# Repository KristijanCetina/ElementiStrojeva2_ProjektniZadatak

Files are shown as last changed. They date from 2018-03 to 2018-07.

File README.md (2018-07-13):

# ElementiStrojeva2_ProjektniZadatak
Projektni zadatak iz kolegija Elementi strojeva 2

Proračun i konstrukcija strojnog sklopa cilindričnog zupčanika s ravnim zubima, vratila i uležištenja unutar prijenosnika snage.
[PDF verzija proračuna s nacrtom](https://github.com/KristijanCetina/ElementiStrojeva2_ProjektniZadatak/blob/master/ProjektniZadatak_KristijanCetina.pdf)

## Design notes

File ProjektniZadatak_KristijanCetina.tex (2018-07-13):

\documentclass[11pt,a4paper]{article}
\usepackage[utf8]{inputenc}
\usepackage[croatian]{babel}
\usepackage{amsmath, amsfonts, amssymb}
\usepackage{tocloft}
\usepackage[hidelinks]{hyperref}
\usepackage[section]{placeins}
\usepackage{graphicx}
\usepackage{float}
\usepackage[final]{pdfpages}
\bibliographystyle{ieeetr}%ieeetr, abbrv
\renewcommand{\cftsecleader}{\cftdotfill{\cftdotsep}}

\newcommand{\kolegij}{Elementi strojeva 2}
\newcommand{\naslovRada}{Projektni zadatak}
\newcommand{\mailFriendlynaslovRada}{Elementi strojeva 2, projektni zadatak}

\author{Kristijan Cetina\footnote{\href{mailto:kcetina@politehnika-pula.hr?subject=\mailFriendlynaslovRada}{kcetina@politehnika-pula.hr}, JMBAG: 2424011721}}
\title{\kolegij \\ \naslovRada}
\date{Pula, \today}

\begin{document}

\begin{titlepage}
\clearpage
\begin{center}
\begin{Huge}
POLITEHNIKA PULA\\
\end{Huge}
\begin{LARGE}
Visoka tehničko-poslovna škola s p.j.\\
Stručni studij politehnike\\
\end{LARGE}
\end{center}
\vspace{3cm}
{\let\newpage\relax\maketitle}
\thispagestyle{empty}
\vfill
\begin{abstract}
U ovom radu predstavljam proračun strojnog sklopa - vratila prijenosnika snage i pripadajućih ležajeva koji je zadan kao sastavni dio kolegija Elementi strojeva 2.
\end{abstract}
\end{titlepage}

\tableofcontents
%\listoftables	%ako ih ima puno prebaci na kraj dokumenta
%\listoffigures	%ako ih ima puno prebaci na kraj dokumenta

\newpage
\section{Uvod}
Ovaj projektni zadatak nastoj je kao obavezni zadatak u sklopu kolegija Elementri strojeva 2 koji se održava pod vodstvom prof. dr. sc. Božidara Križana na stručnom studiju politehnike na Politehnici Pula.

U ovom radu obrađen je proračun vratila prijenosnika snage s pripadajućim ležajevima. Prema zadatku bilo je potrebno odrediti dimenzije vratila i ležaja te odabrati prikladni ležaj u ondnosu na postavljene zahtjeve prenosa snage i traženu minimalnu trajnost.

\newpage
\section{Proračun sklopa}
\subsection{Zadani parametri}
Prema projektnom zadatku zadani su sljedeći parametri sklopa:\\
\begin{tabbing}
\hspace{260pt}\=\kill
 Snaga koju prenose zupčanik i vratilo \> $P=23 kW$ \\ 
 Brzina vrtnje \> $800 min^{-1}$ \\ 
 Materijal vratila \> Ck45 \\
 Korjeni promjer zupčanika \> $d_f=96,25mm$ \\ 
 Diobeni promjer zupčanika \> $d=110mm$ \\ 
 Tjemeni promjer zupčanika \> $d_a=121mm$ \\ 
 Širina zupčanika \> $b_z=115mm$ \\ 
 Faktor sigurnosti \> $\nu_d=1,3$ \\ 
 Hrapavost površine na kritičnim mjestima \> $R_a=0,8\mu m$ \\ 
 Razmak ležajeva \> $l=165mm$ \\ 
 Razmak između središta ležaja A\\ i središta zupčanika \> $a=80mm$ \\ 
 Minimalna trajnost ležajeva \> $L_{10h min}=12000 sati$
\end{tabbing}
Mehanička svojstva korištenog materijala su sljedeća:\\
\begin{align*}
R_{dt0}&=340 \textstyle\frac{N}{mm^2}\\
R_{ds-1}&=370 \textstyle\frac{N}{mm^2}\\
R_e&=490 \textstyle\frac{N}{mm^2}\\
R_m&=700 \textstyle\frac{N}{mm^2}
\end{align*}
 
\subsection{Projektni proračun sklopa}
U projektnom praračunu sklopa ne uzima se u obzir svi detalji sklopa kao niti koncentracije lokalnog naprezanja, ali se zato uzima značajno veći faktor sigurnosti kako bi kompenzirali za izostavljene faktore. U projektnom proračunu za određivanje početnog promjera vratila uzeti su u obzir samo snaga koja se prenosi i materijal od kojeg se izrađuje vratilo. Kao mjerodavne vrijednosti uzeto je torzijsko naprezanje koje mora biti manje od dopuštenog, a faktor sigurnosti je usvojen $\nu=12$.
Kao glavni uvjet uzet je kriterij čvrstoće pri kojem torzijsko naprezanje mora biti manje od dopuštenog pri čemu torzijsko naprezanje možemo izraziti pomoću izraza
\begin{equation}
\tau_t=\dfrac{T}{W_p}\label{equ:tangencijalnoNaprezanje}
\end{equation}
pri čemu je $W_p$ za okrugli puni popreči presjek jednak
\begin{equation}
W_p=\frac{d_1^3 \cdot \pi}{16}
\end{equation}
Okretni moment koji se prenosi izračunat je pomoću sljedećeg izraza
\begin{equation}
T=\frac{P}{\omega}\label{equ:okretniMoment}
\end{equation}
pri čemu je obodna brzina $\omega=2 \cdot \pi \cdot n$, a $n$ je izražen u okretajima u sekundi $[s^{-1}]$.
Uvršavanjem poznatih podataka u \eqref{equ:okretniMoment} dobije se okretni moment
\begin{align*}
T&=\frac{60 \cdot 23 \cdot 10^3}{2 \cdot \pi \cdot 800}\\
T&=\textbf{274,5 Nm}
\end{align*}
Promjer vratila je izračunat pomoću izraza
\begin{equation}
d_1 \geq \sqrt[3]{\dfrac{16 \cdot T \cdot \nu}{R_{dt0} \cdot \pi}} \label{equ:pocetniPromjer}
\end{equation}

Uvršavanjem poznatih podataka u izraz \eqref{equ:pocetniPromjer} dobije se početni promjer vratila $d_1$
\begin{align*}
d_1&\geq \sqrt[3]{\dfrac{16 \cdot 274,5\cdot 10^3 \cdot 12}{340 \cdot \pi}}\\
d_1&\geq \mathbf{36,68 mm} 
\end{align*}

\subsection{Konstruiranje sklopa}
Prema tablici standardnih dimenzija krajeva cilindričnog vratila prema normi DIN 748 usvojena je dimenzija \textbf{38x80 DIN 748} ($\phi38k6$). Maksimalni radijus prijelaza je $r_{max}=1 mm$.

Prema tablici standardnih dimenzija uložnih pera po DIN 6885 normi usvojeno je pero 
$\mathbf{DIN6885-A 10 \times 8 \times 70-E295}$ s dubinom utora u vratilu $t_1=5mm$.
Dimenzija $d_2$ je zbog standardnih dimenzija ležajeva usvojena $\mathbf{d_2=45mm}$
\subsubsection*{Žlijeb za izlaz alata}
Usvojeme dimenzije žlijeba za izlaz alata prema $d_2$ su $\mathbf{DIN \, 509-E \, 0,6 \times 0,3}$ ($\rho_1=0,6mm$, $t_1=0,3mm$). Na slici \ref{izlazAlata} prikazan je žlijeb za izlaz alata.
\begin{figure}[H]
\centering
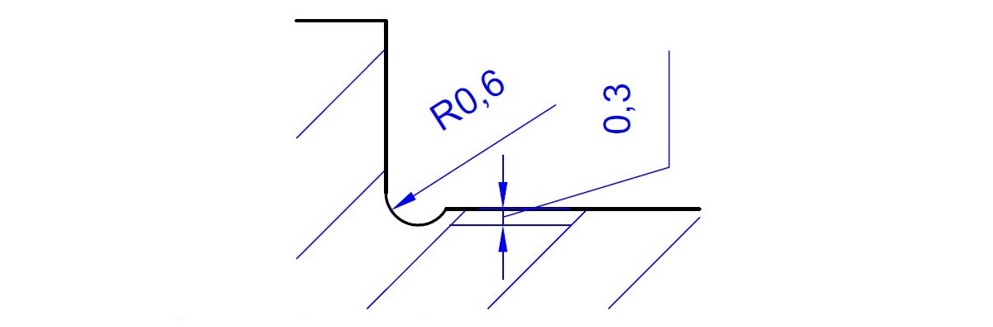
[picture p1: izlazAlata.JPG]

\caption{Skica žlijeba za izlaz alata}\label{izlazAlata}
\end{figure}
\subsubsection*{Visina bočnog oslonca ležaja}
Kao vrijednost visine bočnog oslonca ležaja usvojena je vrijednost $h=3,5mm$.
Promjer $d_3$ je izračunat kao $d_3=d_2+2 \cdot h = \mathbf{52mm}$.
Vrijednost radijusa zakrivljenja $\rho_2$ je usvojen $\rho_2=5mm$.

\subsection{Proračun reakcija u ležajevima}
Tangencijalna sila između zupčanika je izračunata pomoću momenta koji se prenosi i promjera zupčanika
\begin{align*}
F_t&=\frac{2T}{d}\\
F_t&=\frac{2 \cdot 274,5 \cdot 10^3}{110}\\
F_t&=\textbf{4990,9N}
\end{align*}
Radijalna sila je izračunata pomoću tangencijalne sile i poznatog kuta zahvata zubaca zupčanika koji iznosi $\alpha_n=20^\circ$
\begin{align*}
F_r&=F_t \cdot \tan \alpha_n\\
F_r&=4990,9 \cdot \tan 20^\circ\\
F_r&=\textbf{1816,5N}
\end{align*}
Kako sile mođusobno djeluju pod pravim kutem njihova rezultanta se može izračunati po Pitagorinom poučku kao korijen zbroja kvadrata sila
\begin{align*}
F&=\sqrt{F_t^2 + F_r^2}\\
F&=\sqrt{4990,9^2 + 1816,5^2}\\
F&=\textbf{5311,2N}
\end{align*}
Reakcija u osloncu $B$ izračunata je pomoću uvijeta ravnoteže sume momenata oko oslonva $A$
\begin{align*}
F_B&=\frac{F \cdot 80}{168}\\
F_B&=\frac{5311,2N \cdot 80}{168}\\
F_B&=\textbf{2575,1N}
\end{align*}
rakcija u osloncu $A$ izračunata je pomoću uvijeta ravnoteže sustava u kojem je suma sila i reakcija jednaka nuli
\begin{align*}
F_A&=F-F_B\\
F_A&=5311,2-2575,1\\
F_A&=\textbf{2736,1N}
\end{align*}

\subsection{Izbor valjnih ležajeva i proračun stvarne trajnosti}
Trajnost ležajeva se može proračunati po izrazu
\begin{equation}
L_{10h}=\left(\frac{C}{F} \cdot f_t \right)^p \cdot \frac{10^6}{60 \cdot n}
\label{equ:trajnostLezaja}
\end{equation}
pri čemu je $C$ - dinamička nosivost ležaja, $p$ - eksponent vijeka trajanja. Za kuglične ležajeve $p=3$ i $f_t$ - temperaturni faktor. Za $\vartheta < 150^\circ C \Rightarrow f_t=1$.

Iz izraza \eqref{equ:trajnostLezaja} može se izračunati minimalna potrebna dimanička nosivost ležaja
\begin{align*}
C&=\frac{F}{f_t} \cdot \sqrt[3]{\frac{L_{10h} \cdot 60 \cdot n}{10^6}}\\
C&=\frac{2736,1}{1} \cdot \sqrt[3]{\frac{12000 \cdot 60 \cdot 800}{10^6}}\\
C&\cong \mathbf{22,8kN}
\end{align*}
Nakon pregleda kataloških podataka dostupnih ležajeva odabran je ležaj \textbf{SKF 6209} koji ima dinamičku nosivost od $C=35,1kN$.

\begin{figure}[!h]
\centering
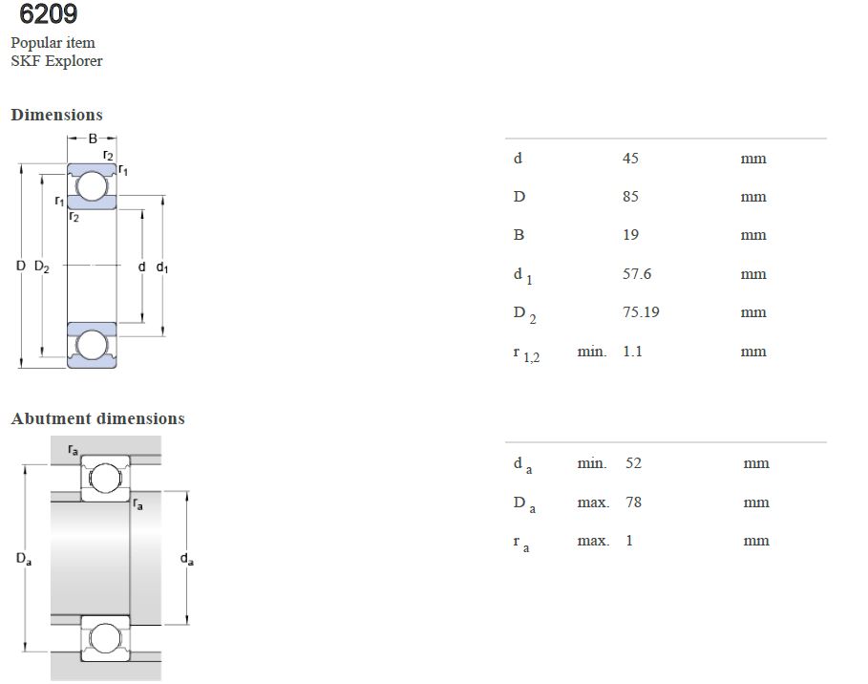
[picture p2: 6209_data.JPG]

\caption{Tehnički podaci odabranog ležaja SKF 6209}\label{6208data}
\end{figure}

\subsubsection*{Proračun stvarne trajnosti}
Po izrazu \eqref{equ:trajnostLezaja} sada se može izračunati stvarna trajnost za odabrani ležaj
\begin{align*}
L_{10h}&=\left(\frac{35100}{2736,1} \cdot 1 \right)^3 \cdot \frac{10^6}{60 \cdot 800}\\
L_{10h}&=\mathbf{43983\, h}
\end{align*}

\newpage

\subsection{Proračun momenata savijanja i naprezanja}
U nastavku su dani proračuni momenata savijanja i naprezanja za svaki kritični presjek nazanačen na slici \ref{KriticniPresjeci}.
\begin{figure}[h]
\centering
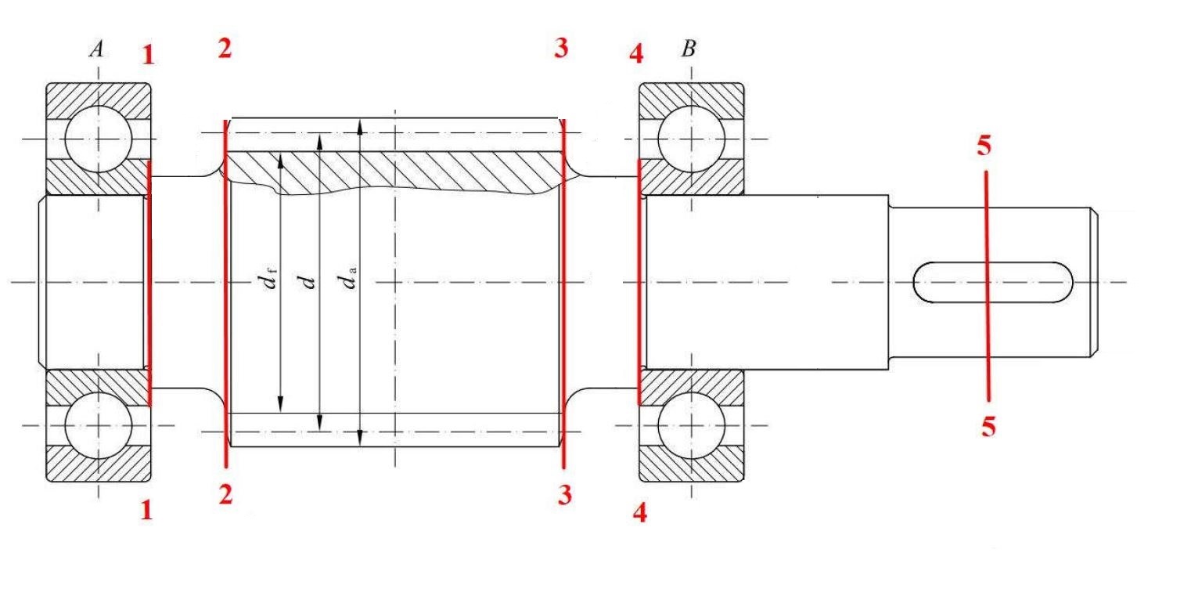
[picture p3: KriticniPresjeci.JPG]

\caption{Prikaz kritičnih presjeka na vratilu}\label{KriticniPresjeci}
\end{figure}
\begin{align*}
M_{S1}=F_A \cdot \frac{B}{2}=2736,1 \cdot \frac{19}{2}&=25933Nmm\\
M_{S2}=F_A \cdot \left(a- \frac{b_z}{2}\right)=2736,1 \cdot \left(80- \frac{115}{2}\right)&=61562,3Nmm\\
M_{S3}=F_B \cdot \left(l-a- \frac{b_z}{2}\right)=2575,1 \cdot \left(165-80- \frac{115}{2}\right)&=70815,3Nmm\\
M_{S4}=F_B \cdot \frac{B}{2}=2575,1 \cdot \frac{19}{2}&=24463,5Nmm\\
M_{S5}&=0
\end{align*}

\subsubsection*{Geometrijske karakteristike poprečnih presjeka - $W$}
\begin{align*}
W_1=W_4=\frac{d_2^3 \cdot \pi}{32}=\frac{45^3 \cdot \pi}{32}&=8946,2mm^3\\
W_2=W_3=\frac{d_3^3 \cdot \pi}{32}=\frac{52^3 \cdot \pi}{32}&=13804,2mm^3
\end{align*}
\subsubsection*{Polarni momenti otpora - $W_p$}
\begin{align*}
W_{p2}=W_{p3}=\frac{d_3^3 \cdot \pi}{16}=\frac{52^3 \cdot \pi}{16}&=27608,3mm^3\\
W_{p4}=\frac{d_2^3 \cdot \pi}{16}=\frac{45^3 \cdot \pi}{16}&=17892,4mm^3\\
W_{p5}=\frac{(d_1-t_1)^3 \cdot \pi}{16}=\frac{(38-5)^3 \cdot \pi}{16}&=7056,2mm^3
\end{align*}
\subsubsection*{presjek 1-1}
$$
\sigma_{s1}=\frac{M_{S1}}{W_1}=\frac{25933}{8946,2}=\mathbf{2,9\textstyle\frac{N}{mm^2}}
$$
\subsubsection*{presjek 2-2}
\begin{align*}
\sigma_{s2}=\frac{M_{S2}}{W_2}=\frac{61562,3}{13804,2}&=4,6\textstyle\frac{N}{mm^2}\\
\tau_{t2} =\frac{T}{W_{p2}}=\frac{274,5 \cdot 10^3}{27608,3}&=9,9\textstyle\frac{N}{mm^2}\\
\sigma_{ekv2}=\sqrt{\sigma_{s2}^2+3 \cdot (0,7 \cdot \tau_{t2})^2}\\
\sigma_{ekv2}=\sqrt{4,6^2+3 \cdot (0,7 \cdot 9,9)^2}&=\mathbf{12,9\textstyle\frac{N}{mm^2}}
\end{align*}
\subsubsection*{presjek 3-3}
\begin{align*}
\sigma_{s3}=\frac{M_{S3}}{W_3}=\frac{70815,3}{13804,2}&=5,1\textstyle\frac{N}{mm^2}\\
\tau_{t3} =\frac{T}{W_{p3}}=\frac{274,5 \cdot 10^3}{27608,3}&=9,9\textstyle\frac{N}{mm^2}\\
\sigma_{ekv3}=\sqrt{\sigma_{s3}^2+3 \cdot (0,7 \cdot \tau_{t3})^2}\\
\sigma_{ekv3}=\sqrt{4,6^2+3 \cdot (0,7 \cdot 9,9)^2}&=\mathbf{13 \textstyle \frac{N}{mm^2}}
\end{align*}
\subsubsection*{presjek 4-4}
\begin{align*}
\sigma_{s4}=\frac{M_{S4}}{W_4}=\frac{23175,9}{8946,2}&=2,6\textstyle\frac{N}{mm^2}\\
\tau_{t4} =\frac{T}{W_{p4}}=\frac{274,5 \cdot 10^3}{17892,4}&=15,3\textstyle\frac{N}{mm^2}\\
\sigma_{ekv4}=\sqrt{\sigma_{s4}^2+3 \cdot (0,7 \cdot \tau_{t4})^2}\\
\sigma_{ekv4}=\sqrt{2,6^2+3 \cdot (0,7 \cdot 15,3)^2}&=\mathbf{18,7 \textstyle\frac{N}{mm^2}}
\end{align*}
\subsubsection*{presjek 5-5}
$$
\tau_{t5} =\frac{T}{W_{p5}}=\frac{274,5 \cdot 10^3}{7056,2}=\mathbf{38,9\textstyle\frac{N}{mm^2}}
$$

\section{Kontrolni proračun vratila}
Dopušteno naprezanje pri savijanju u kontrolnom proračunu uzima u obzir trajnu izmjeničnu dinamičku čvrstoću materijala pri savijanju, faktore $b_{1 \sigma}$ - faktor utjecaja poršinske hrapavosti za vlak/tlak i savijanje, $b_2$ - faktor utjecaja veličine konstrukcijskog elementa, $\nu_d$ - faktor sigurnosti prikladan za kontrolni proračun te $\beta_{ks}$ - efektivni faktor koncentracije naprezanja pri savijanju i to sve u sljedećem izrazu
\begin{equation}
\sigma_{sdop}=\frac{R_{ds-1} \cdot b_{1 \sigma} \cdot b_2}{\nu_d \cdot \beta_{ks}}\label{equ:dozvoljenoNaprezanje_kontrolni_savijanje}
\end{equation}
Za izračunati dopušteno naprezanje potrebni su i sljedeći podaci
\begin{align*}
R_z&=4 \cdot R_a\\
R_z&=4 \cdot 0,8 \mu m\\
R_z&=\mathbf{3,2 \mu m}
\end{align*}
Faktor $b_{1 \sigma}$ vrijedi isti za cijeli sklop jer je navedeni kompletan izrađen od istog materijala jednake površinske obrade, a izračunat je po sljedećem izrazu
\begin{align*}
b_{1 \sigma}&=1-0,22 \cdot \log R_z \left( \log \frac{R_m}{20}-1 \right)\\
b_{1 \sigma}&=1-0,22 \cdot \log 3,2 \left( \log \frac{700}{20}-1 \right)\\
b_{1 \sigma}&=\mathbf{0,939}
\end{align*}
Efektivni faktor koncentracije naprezanja pri savijanju $\beta_{ks}$ se računa za svaki kritični presjek i to po izrazu
\begin{equation}
\beta_{ks}=1+ \eta_k \cdot (\alpha_{ks}-1)\label{equ:beta_KS}
\end{equation}
Faktor osjetljivosti materijala na koncentraciju naprezanja $\eta_k$ se računa po sljedećem izrazu
\begin{equation}
\eta_k=\frac{1}{1+\frac{8}{\rho} \cdot \left( 1- \frac{R_e}{R_m} \right)^3}\label{equ:eta_K}
\end{equation}
Geometrijski faktor koncentracije naprezanja pri savijanju $\alpha_{ks}$ je očitan iz skripte, slika 8 na stranici 6. Faktor utjecaja veličine konstrukcijskog elementa $b_2$ je očitan iz slike 7, stranica 5 skripte.

\subsubsection*{presjek 1-1}
Zakrivljenost žlijeba za izlaz alata je $\rho_1=0,6mm$, vrijednost geometrijskog faktora koncentracije naprezanja pri savijanju je očitana $\alpha_{ks}=3,1$ i faktor utjecaja veličine konstrukcijskog elementa je $d_2=45mm \Rightarrow b_2=0,835$.
Kada se uvrste poznati podaci u \eqref{equ:eta_K} faktor osjetljivosti materijala na koncentraciju naprezanja $\eta_k$ za navedene presjeke iznosi
\begin{align*}
\eta_k&=\frac{1}{1+\frac{8}{0,6} \cdot \left( 1- \frac{490}{700} \right)^3}\\
\eta_k&=0,735
\end{align*}
$\alpha_{ks}$ je očitan iz slike 8 na stranici 6 s slijedećim parametrima:
\begin{align*}
d&=d_2-t_1=44,7mm\\
D&=d_3=52mm\\
\rho&=1mm\\
t&=\dfrac{D-d}{2}=3,65mm
\end{align*}
Uvršatavnjem poznatih podataka u \eqref{equ:beta_KS} dobije se
\begin{align*}
\beta_{ks}&=1+ 0,735 \cdot (3,1-1)\\
\beta_{ks}&=2,54
\end{align*}
Slijednom navedenog može se izračunati dopušteno naprezanje za navedene presjeke uvrštavanjem poznatih podataka u izraz \eqref{equ:dozvoljenoNaprezanje_kontrolni_savijanje}
\begin{align*}
\sigma_{sdop1}&=\frac{370 \cdot 0,939 \cdot 0,835}{1,3 \cdot 2,54}\\
\sigma_{sdop1}&=\mathbf{88\textstyle\frac{N}{mm^2}}\\
\sigma_{sdop1}&>\sigma_{s1}
\end{align*}
Vidljivo je kako dopušteno naprezanje iznosi više od ekvivalentnih naprezanja koji se javljaju u danim presjecima te da oni zadovoljavaju kriterij čvrstoće.

\subsubsection*{presjek 2-2}
Za dane presjeke $d_3=52mm \Rightarrow b_2=0,814$, zakrivljenje $\rho=5mm$ i $\alpha_{ks}=1,9$.
Uvršatanjem poznatih podataka u \eqref{equ:eta_K} faktor osjetljivosti materijala na koncentraciju naprezanja $\eta_k$ za navedene presjeke iznosi
\begin{align*}
\eta_k&=\frac{1}{1+\frac{8}{5} \cdot \left( 1- \frac{490}{700} \right)^3}\\
\eta_k&=0,956
\end{align*}
$\alpha_{ks}$ je očitan iz slike 8 na stranici 6 s slijedećim parametrima:
\begin{align*}
d&=d_3=47mm\\
D&=d_f=96,25mm\\
\rho&=\rho_2=5mm\\
t&=\dfrac{D-d}{2}=22,125mm
\end{align*}
Uvršatavnjem poznatih podataka u \eqref{equ:beta_KS} dobije se
\begin{align*}
\beta_{ks}&=1+ 0,956 \cdot (1,9-1)\\
\beta_{ks}&=1,86
\end{align*}
Slijednom izračunatog može se izračunati dopušteno naprezanje za navedene presjeke uvrštavanjem poznatih podataka u izraz \eqref{equ:dozvoljenoNaprezanje_kontrolni_savijanje}
\begin{align*}
\sigma_{sdop}&=\frac{370 \cdot 0,939 \cdot 0,814}{1,3 \cdot 1,86}\\
\sigma_{sdop}&=\mathbf{117\textstyle\frac{N}{mm^2}}
\end{align*}
Vidljivo je kako dopušteno naprezanje iznosi više od ekvivalentnih naprezanja koji se javljaju u danim presjecima te da oni zadovoljavaju kriterij čvrstoće.

\subsubsection*{presjek 3-3}
U pogledu konstrukcijskih karakteristika i naprezanaja presjeci 2-2 i 3-3 mogu se smatrati jednakima te je stoga i njihovo dopušteno naprezanje jednako.
\begin{align*}
\sigma_{sdop3}&=\sigma_{sdop2}\\
\sigma_{sdop3}&>\sigma_{s3}
\end{align*}

\subsubsection*{presjek 4-4}
U pogledu konstrukcijskih karakteristika i naprezanaja presjeci 1-1 i 4-4 mogu se smatrati jednakima te je stoga i njihovo dopušteno naprezanje jednako.
\begin{align*}
\sigma_{sdop4}&=\sigma_{sdop1}\\
\sigma_{sdop4}&>\sigma_{s4}
\end{align*}

\subsubsection*{presjek 5-5}
U presjeku 5-5 djeluje samo torzijsko naprezanje te se dopušteno naprezanje računa s podacima za tu vrstu naprezanja po izrazu
\begin{equation}
\tau_{tdop}=\frac{R_{dt0} \cdot b_{1 \tau} \cdot b_2}{\nu_d \cdot \beta_{kt}}\label{equ:dozvoljenoNaprezanje_kontrolni_torzija}
\end{equation}
pri čemu su $R_{dt0}$ - trajna ishodišna dinamička čvrstoča pri torziji, $b_{1 \tau}$ - faktor utjecaja površinske hrapavosti za torziju i $\beta_{kt}$ - efektivni faktor koncentracije naprezanja pri torziji.
Efektivni faktor koncentracije naprezanja pri torziji $\beta_{kt}$ računa se po izrazu
\begin{equation}
\beta_{kt}=1+ \eta_k \cdot (\alpha_{kt}-1)\label{equ:beta_KT}
\end{equation}
Za zadani presjek $d_1=38mm \Rightarrow b_2=0,856$, iz slike 7, stranica 10 skripte očatani su $\alpha_{kt}=2,8$ i $\rho=0,25mm$.
$b_{1 \tau}$ - faktor utjecaja poršinske hrapavosti za torziju izračunat je po izrazu
\begin{align*}
b_{1 \tau}&=0,575 \cdot b_{1 \sigma} + 0,425\\
b_{1 \tau}&=0,575 \cdot 0,939 + 0,425\\
b_{1 \tau}&=0,965
\end{align*}
Uvršatanjem poznatih podataka u \eqref{equ:eta_K} faktor osjetljivosti materijala na koncentraciju naprezanja $\eta_k$ za navedeni presjek iznosi
\begin{align*}
\eta_k&=\frac{1}{1+\frac{8}{0,25} \cdot \left( 1- \frac{490}{700} \right)^3}\\
\eta_k&=0,54
\end{align*}
Uvršatavnjem poznatih podataka u \eqref{equ:beta_KT} dobije se
\begin{align*}
\beta_{kt}&=1+ 0,54 \cdot (2,8-1)\\
\beta_{kt}&=1,97
\end{align*}
Slijednom izračunatog može se izračunati dopušteno naprezanje za navedeni presjek uvrštavanjem poznatih podataka u izraz \eqref{equ:dozvoljenoNaprezanje_kontrolni_torzija}
\begin{align*}
\tau_{tdop}&=\frac{340 \cdot 0,965 \cdot 0,856}{1,3 \cdot 1,97}\\
\tau_{tdop}&=\mathbf{109,7\textstyle\frac{N}{mm^2}}\\
\tau_{tdop}&>\tau_{t5}
\end{align*}
Vidljivo je kako dopušteno naprezanje iznosi više od torzijskog naprezanja koji se javlja u danom presjeku te da isti zadovoljavaja kriterij čvrstoće.

\newpage
\nocite{*}
\addcontentsline{toc}{section}{Literatura}
\bibliography{literatura}

\newpage
%\appendix
%\section{Radionički nacrt vratila}
\addcontentsline{toc}{section}{Dodatak A: Radionički nacrt sklopa}
%{\Large \textbf{Dodatak A: Radionički nacrt sklopa}}
\includepdf[fitpaper]{StrojniSklopNacrt.pdf}
%\input{filename} (da nastavi pisati kako da je copy/paste) ili
%\include{filename} (da ubaci na novu stranicu. Ok za nova poglavlja i sl)
\end{document}

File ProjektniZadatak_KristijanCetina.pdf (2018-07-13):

# POLITEHNIKA PULA

Visoka tehničko-poslovna škola s p.j.

## Stručni studij politehnike

## Elementi strojeva 2 Projektni zadatak

Kristijan Cetina∗

Pula, 13. srpnja 2018.

Sažetak

U ovom radu predstavljam proračun strojnog sklopa - vratila prijenosnika snage i pripadajućih ležajeva koji je zadan kao sastavni dio kolegija Elementi strojeva 2.

∗
kcetina@politehnika-pula.hr, JMBAG: 2424011721

## Sadržaj

1

## 1 Uvod

Ovaj projektni zadatak nastoj je kao obavezni zadatak u sklopu kolegija Elementri strojeva 2 koji se održava pod vodstvom prof. dr. sc. Božidara Križana na stručnom studiju politehnike na Politehnici Pula.
U ovom radu obraden je proračun vratila prijenosnika snage s pripadajućim ležajevima. Prema zadatku bilo je potrebno odrediti dimenzije vratila i ležaja te odabrati prikladni ležaj u ondnosu na postavljene zahtjeve prenosa snage i traženu minimalnu trajnost.

2

## 2 Proračun sklopa

### 2.1 Zadani parametri

Prema projektnom zadatku zadani su sljedeći parametri sklopa:

Snaga koju prenose zupčanik i vratilo | P = 23kW
Brzina vrtnje | 800min⁻¹
Materijal vratila | Ck45
Korjeni promjer zupčanika | df = 96, 25mm
Diobeni promjer zupčanika | d = 110mm
Tjemeni promjer zupčanika | da = 121mm
Sirina zupčanika ˇ | bz = 115mm
Faktor sigurnosti | νd = 1, 3
Hrapavost površine na kritičnim mjestima | Ra = 0, 8µm
Razmak ležajeva | l = 165mm
Razmak izmedu središta ležaja A
i središta zupčanika | a = 80mm
Minimalna trajnost ležajeva | L10hmin = 12000sati

Mehanička svojstva korištenog materijala su sljedeća:

Rdt0 = 340 N
mm²
Rds−1 = 370 N
mm²
Re = 490 N
mm²
Rm = 700 N
mm²

### 2.2 Projektni proračun sklopa

U projektnom praračunu sklopa ne uzima se u obzir svi detalji sklopa kao niti koncentracije lokalnog naprezanja, ali se zato uzima značajno veći faktor sigurnosti kako bi kompenzirali za izostavljene faktore. U projektnom proračunu za odredivanje početnog promjera vratila uzeti su u obzir samo snaga koja se prenosi i materijal od kojeg se izraduje vratilo. Kao mjerodavne vrijednosti uzeto je torzijsko naprezanje koje mora biti manje od dopuštenog, a faktor sigurnosti je usvojen ν = 12. Kao glavni uvjet uzet je kriterij čvrstoće pri kojem torzijsko naprezanje mora biti manje od dopuštenog pri čemu torzijsko naprezanje možemo izraziti pomoću izraza

τt =

T
Wp

(1)

pri čemu je Wp za okrugli puni popreči presjek jednak

Wp =

d

3/1· π
16

(2)

3

Okretni moment koji se prenosi izračunat je pomoću sljedećeg izraza

T =

P
ω

(3)

pri čemu je obodna brzina ω = 2·π ·n, a n je izražen u okretajima u sekundi [s

−1
]. Uvršavanjem poznatih podataka u (3) dobije se okretni moment

T =

60 · 23 · 10³
2 · π · 800
T = 274,5 Nm

Promjer vratila je izračunat pomoću izraza

d1 ≥

3

r
16 · T · ν

Rdt0 · π

(4)

Uvršavanjem poznatih podataka u izraz (4) dobije se početni promjer vratila d1

d1 ≥

3

r
16 · 274, 5 · 10³
- 12
340 · π
d1 ≥ 36, 68mm

### 2.3 Konstruiranje sklopa

Prema tablici standardnih dimenzija krajeva cilindričnog vratila prema normi DIN 748 usvojena je dimenzija 38x80 DIN 748 (φ38k6). Maksimalni radijus prijelaza je rmax = 1mm.
Prema tablici standardnih dimenzija uložnih pera po DIN 6885 normi usvojeno je pero DIN6885 − A10 × 8 × 70 − E295 s dubinom utora u vratilu t1 = 5mm. Dimenzija d2 je zbog standardnih dimenzija ležajeva usvojena d2 = 45mm

Zlijeb za izlaz alata ˇ

Usvojeme dimenzije žlijeba za izlaz alata prema d2 su DIN 509 − E 0, 6 × 0, 3 (ρ1 = 0, 6mm, t1 = 0, 3mm). Na slici 1 prikazan je žlijeb za izlaz alata.

4


Slika 1: Skica žlijeba za izlaz alata

Visina bočnog oslonca ležaja

Kao vrijednost visine bočnog oslonca ležaja usvojena je vrijednost h = 3, 5mm. Promjer d3 je izračunat kao d3 = d2 + 2 · h = 52mm. Vrijednost radijusa zakrivljenja ρ2 je usvojen ρ2 = 5mm.

### 2.4 Proračun reakcija u ležajevima

Tangencijalna sila izmedu zupčanika je izračunata pomoću momenta koji se prenosi i promjera zupčanika

Ft =

2T
d

Ft =

2 · 274, 5 · 10³

110
Ft = 4990,9N

Radijalna sila je izračunata pomoću tangencijalne sile i poznatog kuta zahvata zubaca zupčanika koji iznosi αn = 20◦

Fr = Ft

- tan αn
Fr = 4990, 9 · tan 20◦

Fr = 1816,5N

Kako sile modusobno djeluju pod pravim kutem njihova rezultanta se može izračunati po Pitagorinom poučku kao korijen zbroja kvadrata sila

F =

q
F

2
t + F²
r
F =

p
4990, 9

2 + 1816, 5

2

F = 5311,2N

5

Reakcija u osloncu B izračunata je pomoću uvijeta ravnoteže sume momenata oko oslonva A

FB =

F · 80
168

FB =

5311, 2N · 80
168
FB = 2575,1N

rakcija u osloncu A izračunata je pomoću uvijeta ravnoteže sustava u kojem je suma sila i reakcija jednaka nuli

FA = F − FB
FA = 5311, 2 − 2575, 1

FA = 2736,1N

### 2.5 Izbor valjnih ležajeva i proračun stvarne trajnosti

Trajnost ležajeva se može proračunati po izrazu

L10h =

C
F
- ft

p
·

10⁶
60 · n

(5)

pri čemu je C - dinamička nosivost ležaja, p - eksponent vijeka trajanja. Za kuglične ležajeve p = 3 i ft - temperaturni faktor. Za ϑ < 150◦C ⇒ ft = 1. Iz izraza (5) može se izračunati minimalna potrebna dimanička nosivost ležaja

C =

F
ft

·

3

r
L10h · 60 · n
10⁶

C =

2736, 1
1

·

3

r
12000 · 60 · 800
10⁶
C ∼= 22, 8kN

Nakon pregleda kataloških podataka dostupnih ležajeva odabran je ležaj SKF 6209 koji ima dinamičku nosivost od C = 35, 1kN.

Proračun stvarne trajnosti

Po izrazu (5) sada se može izračunati stvarna trajnost za odabrani ležaj

L10h =

35100
2736, 1
- 1

3
·

10⁶
60 · 800

L10h = 43983 h

6


Slika 2: Tehnički podaci odabranog ležaja SKF 6209

### 2.6 Proračun momenata savijanja i naprezanja

U nastavku su dani proračuni momenata savijanja i naprezanja za svaki kritični presjek nazanačen na slici 3.

MS1 = FA ·

B
2

= 2736, 1 ·

19
2

= 25933Nmm

MS2 = FA ·

a −

bz
2
= 2736, 1 ·
80 −

115
2
= 61562, 3Nmm

MS3 = FB ·

l − a −

bz
2
= 2575, 1 ·
165 − 80 −

115
2
= 70815, 3Nmm

MS4 = FB ·

B
2

= 2575, 1 ·

19
2

= 24463, 5Nmm

MS5 = 0

7


Slika 3: Prikaz kritičnih presjeka na vratilu

Geometrijske karakteristike poprečnih presjeka - W

W1 = W4 =

d

3/2· π
32

=

45³
- π
32

= 8946, 2mm³

W2 = W3 =

d

3/3· π
32

=

52³
- π
32

= 13804, 2mm³

Polarni momenti otpora - Wp

Wp2 = Wp3 =

d

3/3· π
16

=

52³
- π
16

= 27608, 3mm³

Wp4 =

d

3/2· π
16

=

45³
- π
16

= 17892, 4mm³

Wp5 =

(d1 − t1)

3
- π
16

=

(38 − 5)³
- π
16

= 7056, 2mm³

presjek 1-1

σs1 =

MS1
W1

=

25933
8946, 2

= 2, 9

N
mm²

8

presjek 2-2

σs2 =

MS2
W2

=

61562, 3
13804, 2

= 4, 6

N
mm²

τt2 =

T

Wp2

=

274, 5 · 10³

27608, 3

= 9, 9

N
mm²

σekv2 =

q
σ

2
s2 + 3 · (0, 7 · τt2)

2

σekv2 =

p
4, 6

2 + 3 · (0, 7 · 9, 9)² = 12, 9

N
mm²

presjek 3-3

σs3 =

MS3
W3

=

70815, 3
13804, 2

= 5, 1

N
mm²

τt3 =

T

Wp3

=

274, 5 · 10³

27608, 3

= 9, 9

N
mm²

σekv3 =

q
σ

2
s3 + 3 · (0, 7 · τt3)

2

σekv3 =

p
4, 6

2 + 3 · (0, 7 · 9, 9)² = 13 N
mm²

presjek 4-4

σs4 =

MS4
W4

=

23175, 9
8946, 2

= 2, 6

N
mm²

τt4 =

T

Wp4

=

274, 5 · 10³

17892, 4

= 15, 3

N
mm²

σekv4 =

q
σ

2
s4 + 3 · (0, 7 · τt4)

2

σekv4 =

p
2, 6

2 + 3 · (0, 7 · 15, 3)² = 18, 7

N
mm²

presjek 5-5

τt5 =

T

Wp5

=

274, 5 · 10³

7056, 2

= 38, 9

N
mm²

## 3 Kontrolni proračun vratila

Dopušteno naprezanje pri savijanju u kontrolnom proračunu uzima u obzir trajnu izmjeničnu dinamičku čvrstoću materijala pri savijanju, faktore b1σ
- faktor utjecaja poršinske hrapavosti za vlak/tlak i savijanje, b2 - faktor utjecaja veličine konstrukcijskog elementa, νd - faktor sigurnosti prikladan

9

za kontrolni proračun te βks - efektivni faktor koncentracije naprezanja pri savijanju i to sve u sljedećem izrazu

σsdop =

Rds−1 · b1σ · b2

νd · βks

(6)

Za izračunati dopušteno naprezanje potrebni su i sljedeći podaci

Rz = 4 · Ra
Rz = 4 · 0, 8µm

Rz = 3, 2µm

Faktor b1σ vrijedi isti za cijeli sklop jer je navedeni kompletan izraden od istog materijala jednake površinske obrade, a izračunat je po sljedećem izrazu

b1σ = 1 − 0, 22 · log Rz

log Rm
20

− 1

b1σ = 1 − 0, 22 · log 3, 2

log 700
20

− 1

b1σ = 0, 939

Efektivni faktor koncentracije naprezanja pri savijanju βks se računa za svaki kritični presjek i to po izrazu

βks = 1 + ηk · (αks − 1) | (7)

Faktor osjetljivosti materijala na koncentraciju naprezanja ηk se računa po sljedećem izrazu

ηk =

1

1 + 8
ρ

·

1 −

Re
Rm

3

(8)

Geometrijski faktor koncentracije naprezanja pri savijanju αks je očitan iz skripte, slika 8 na stranici 6. Faktor utjecaja veličine konstrukcijskog elementa b2 je očitan iz slike 7, stranica 5 skripte.

presjek 1-1

Zakrivljenost žlijeba za izlaz alata je ρ1 = 0, 6mm, vrijednost geometrijskog faktora koncentracije naprezanja pri savijanju je očitana αks = 3, 1 i faktor utjecaja veličine konstrukcijskog elementa je d2 = 45mm ⇒ b2 = 0, 835. Kada se uvrste poznati podaci u (8) faktor osjetljivosti materijala na koncentraciju naprezanja ηk za navedene presjeke iznosi

ηk =

1
1 + 8
0,6

·

1 −

490

700 3

ηk = 0, 735

10 αks je očitan iz slike 8 na stranici 6 s slijedećim parametrima:

d = d2 − t1 = 44, 7mm

D = d3 = 52mm
ρ = 1mm

t =

D − d
2

= 3, 65mm

Uvršatavnjem poznatih podataka u (7) dobije se

βks = 1 + 0, 735 · (3, 1 − 1)

βks = 2, 54

Slijednom navedenog može se izračunati dopušteno naprezanje za navedene presjeke uvrštavanjem poznatih podataka u izraz (6)

σsdop1 =

370 · 0, 939 · 0, 835
1, 3 · 2, 54

σsdop1 = 88 N
mm²
σsdop1 > σs1

Vidljivo je kako dopušteno naprezanje iznosi više od ekvivalentnih naprezanja koji se javljaju u danim presjecima te da oni zadovoljavaju kriterij čvrstoće.

presjek 2-2

Za dane presjeke d3 = 52mm ⇒ b2 = 0, 814, zakrivljenje ρ = 5mm i αks = 1, 9. Uvršatanjem poznatih podataka u (8) faktor osjetljivosti materijala na koncentraciju naprezanja ηk za navedene presjeke iznosi

ηk =

1
1 + 8
5

·

1 −

490

700 3

ηk = 0, 956

αks je očitan iz slike 8 na stranici 6 s slijedećim parametrima:

d = d3 = 47mm
D = df = 96, 25mm
ρ = ρ2 = 5mm

t =

D − d
2

= 22, 125mm

Uvršatavnjem poznatih podataka u (7) dobije se

βks = 1 + 0, 956 · (1, 9 − 1)

βks = 1, 86

11

Slijednom izračunatog može se izračunati dopušteno naprezanje za navedene presjeke uvrštavanjem poznatih podataka u izraz (6)

σsdop =

370 · 0, 939 · 0, 814
1, 3 · 1, 86
σsdop = 117 N
mm²

Vidljivo je kako dopušteno naprezanje iznosi više od ekvivalentnih naprezanja koji se javljaju u danim presjecima te da oni zadovoljavaju kriterij čvrstoće.

presjek 3-3

U pogledu konstrukcijskih karakteristika i naprezanaja presjeci 2-2 i 3-3 mogu se smatrati jednakima te je stoga i njihovo dopušteno naprezanje jednako.

σsdop3 = σsdop2

σsdop3 > σs3

presjek 4-4

U pogledu konstrukcijskih karakteristika i naprezanaja presjeci 1-1 i 4-4 mogu se smatrati jednakima te je stoga i njihovo dopušteno naprezanje jednako.

σsdop4 = σsdop1

σsdop4 > σs4

presjek 5-5

U presjeku 5-5 djeluje samo torzijsko naprezanje te se dopušteno naprezanje računa s podacima za tu vrstu naprezanja po izrazu

τtdop =

Rdt0 · b1τ · b2

νd · βkt

(9)

pri čemu su Rdt0 - trajna ishodišna dinamička čvrstoča pri torziji, b1τ - faktor utjecaja površinske hrapavosti za torziju i βkt - efektivni faktor koncentracije naprezanja pri torziji. Efektivni faktor koncentracije naprezanja pri torziji βkt računa se po izrazu

βkt = 1 + ηk · (αkt − 1) | (10)

12

Za zadani presjek d1 = 38mm ⇒ b2 = 0, 856, iz slike 7, stranica 10 skripte očatani su αkt = 2, 8 i ρ = 0, 25mm. b1τ - faktor utjecaja poršinske hrapavosti za torziju izračunat je po izrazu

b1τ = 0, 575 · b1σ + 0, 425 b1τ = 0, 575 · 0, 939 + 0, 425

b1τ = 0, 965

Uvršatanjem poznatih podataka u (8) faktor osjetljivosti materijala na koncentraciju naprezanja ηk za navedeni presjek iznosi

ηk =

1
1 + 8
0,25 ·
1 −

490

700 3

ηk = 0, 54

Uvršatavnjem poznatih podataka u (10) dobije se

βkt = 1 + 0, 54 · (2, 8 − 1)

βkt = 1, 97

Slijednom izračunatog može se izračunati dopušteno naprezanje za navedeni presjek uvrštavanjem poznatih podataka u izraz (9)

τtdop =

340 · 0, 965 · 0, 856
1, 3 · 1, 97
τtdop = 109, 7

N
mm²
τtdop > τt5

Vidljivo je kako dopušteno naprezanje iznosi više od torzijskog naprezanja koji se javlja u danom presjeku te da isti zadovoljavaja kriterij čvrstoće.

13

## Literatura

[1] B. Križan, Interna skripta iz kolegija Elementi strojeva 2 za konstrukcijske vježbe. Politehnika Pula, 2018.
[2] B. Križan, Osnove proračuna i oblikovanja konstrukcijskih elemenata. Skolska knjiga, Zagreb, 2008. ˇ

14

1

2

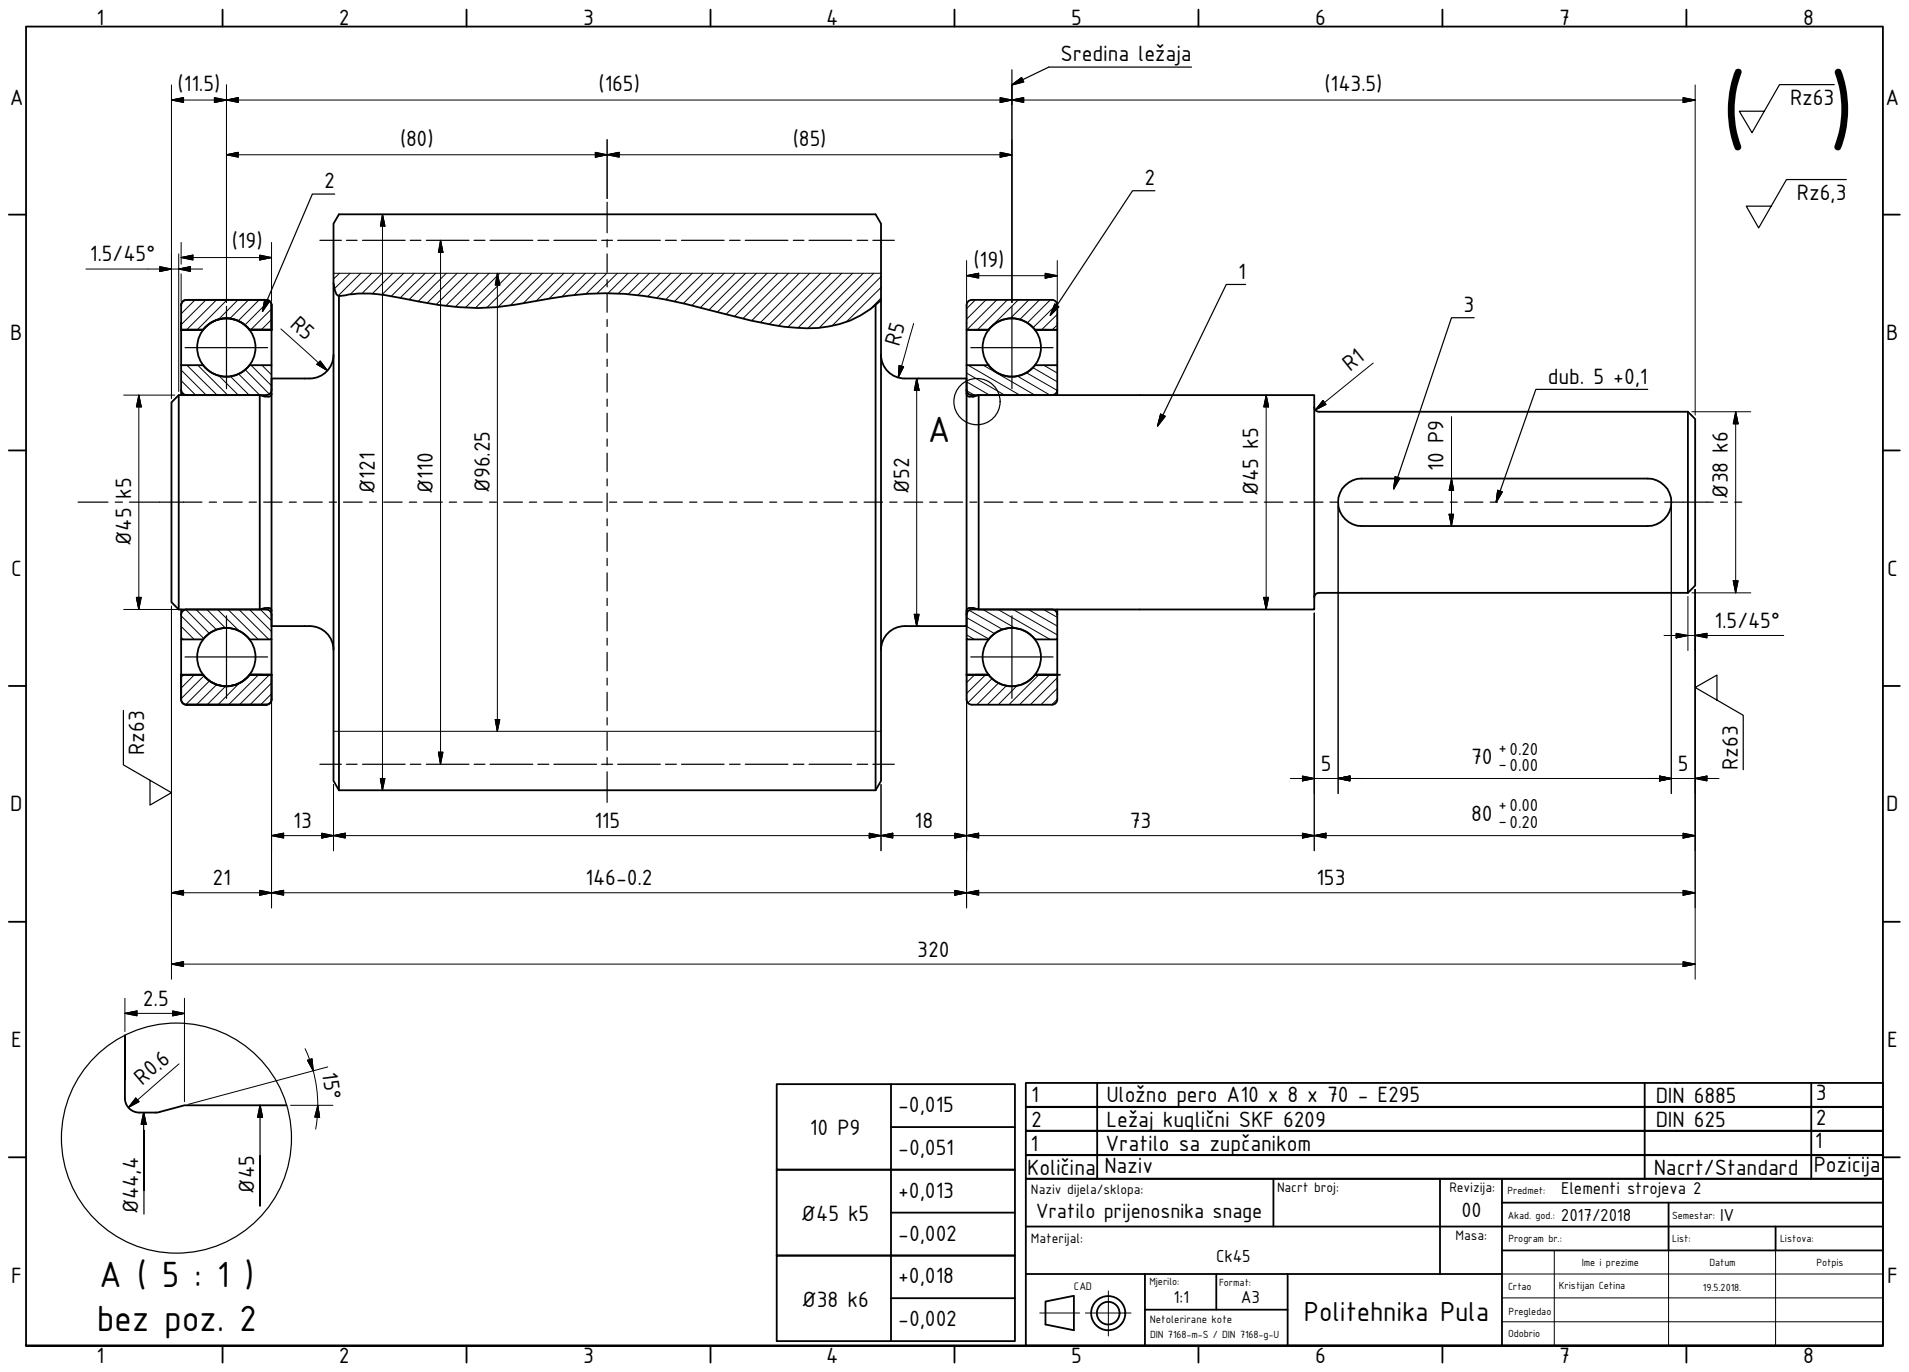
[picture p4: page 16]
A ( 5 : 1 ) bez poz. 2; F CAD; Netolerirane kote; DIN 7168-m-S / DIN 7168-g-U; Pregledao; Odobrio; dub. 5 +0,1; Koliúina; Naziv; Nacrt/Standard; Pozicija; Vratilo sa zupúanikom; Leaj kugliúni SKF 6209; DIN 625; Ulono pero A10 x 8 x 70 - E295; DIN 6885

Sredina leaja

Naziv dijela/sklopa: Vratilo prijenosnika snage | Nacrt broj: | Revizija: 00 | Elementi strojeva 2 Predmet:

2017/2018 Akad. god.: | IV Semestar:

Materijal: Ck45 | Masa: | Program br.: | List: | Listova:

Ime i prezime | Datum | Potpis

Mjerilo: 1:1 | Format: A3 | Politehnika Pula | Crtao | Kristijan Cetina | 19.5.2018.

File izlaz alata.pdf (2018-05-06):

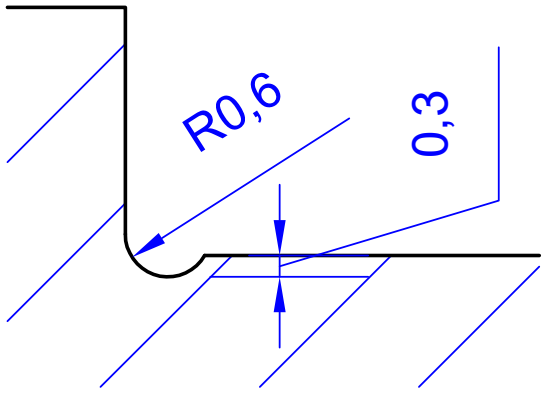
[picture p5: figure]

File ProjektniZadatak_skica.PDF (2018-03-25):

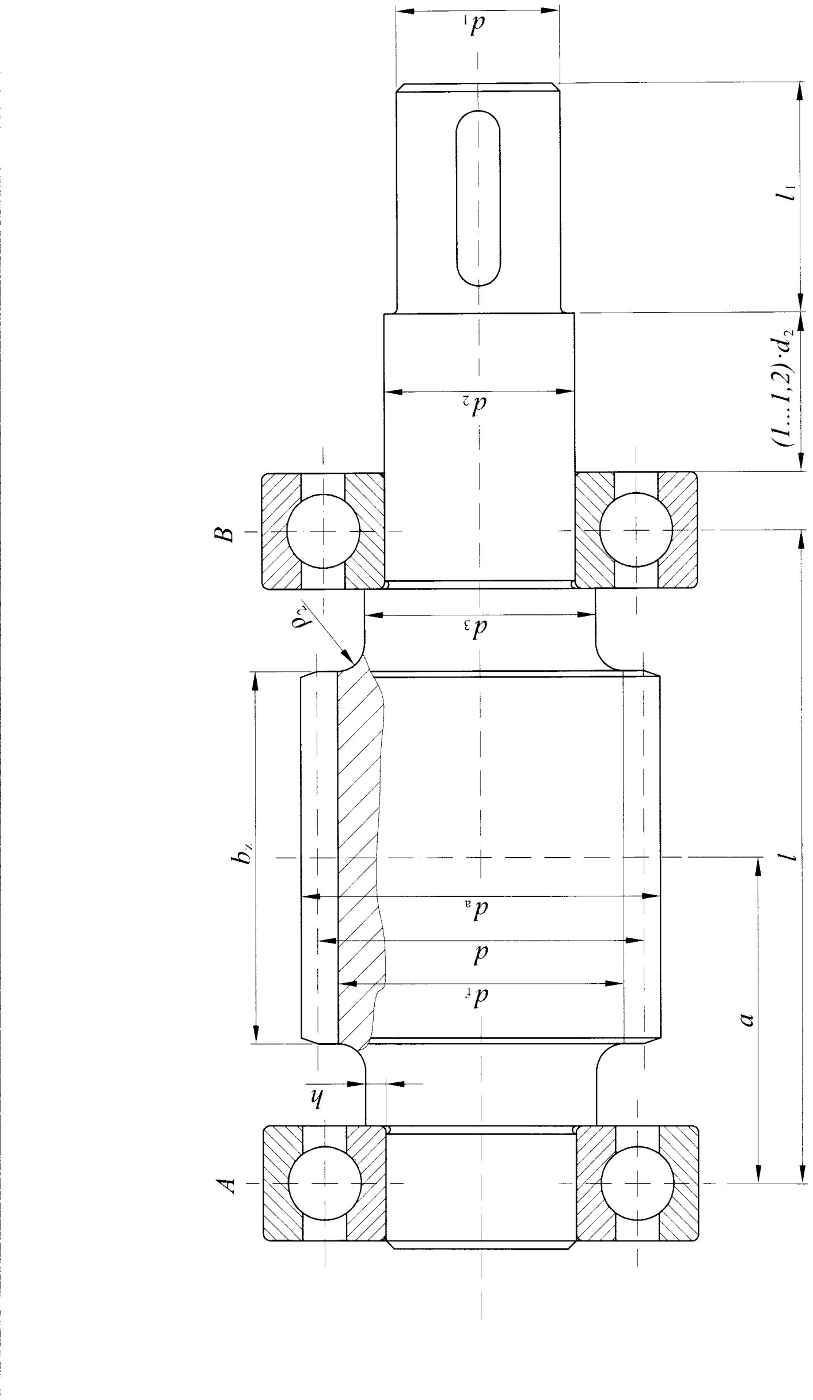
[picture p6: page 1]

N
>i
-'
\'s
,pIlilIIl

---T-

---I I

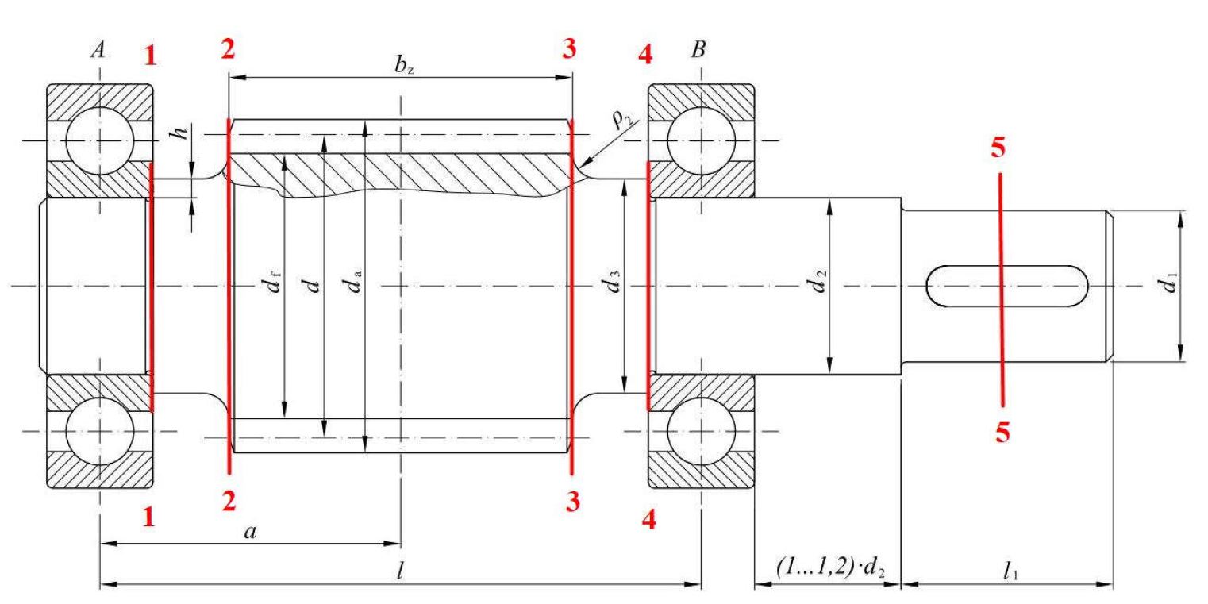
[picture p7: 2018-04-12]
KriticniPresjeci_kotirano.JPG

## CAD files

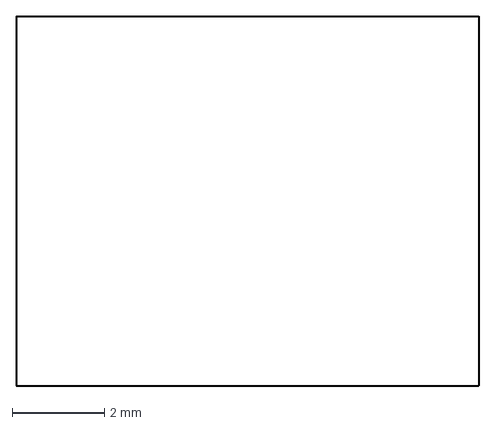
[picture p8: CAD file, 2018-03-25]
KIPP_K0696110X70/K0696.110X70_left.dxf
10.0 x 8.00 mm

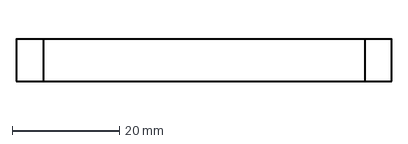
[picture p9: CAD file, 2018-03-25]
KIPP_K0696110X70/K0696.110X70_back.dxf
70.0 x 8.00 mm

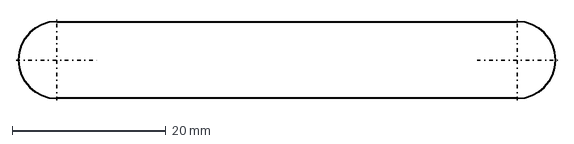
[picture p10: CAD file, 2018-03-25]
KIPP_K0696110X70/K0696.110X70_bottom.dxf
70.5 x 10.5 mm

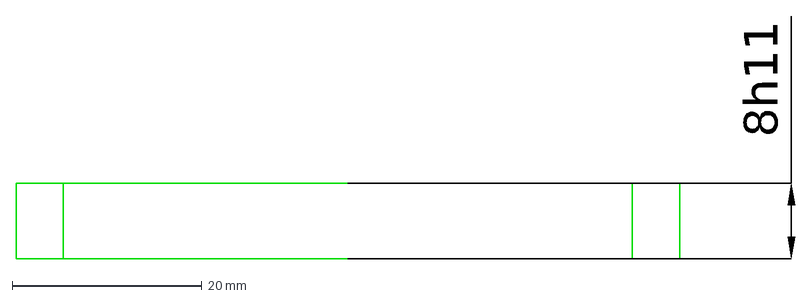
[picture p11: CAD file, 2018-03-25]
KIPP_K0696110X70/K0696.110X70_front.dxf
8h11

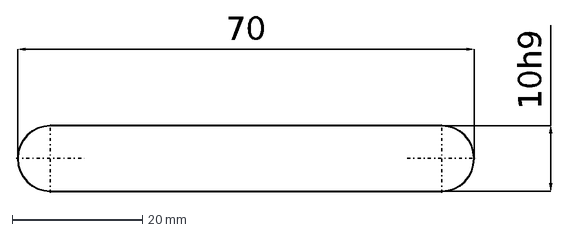
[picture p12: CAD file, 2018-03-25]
KIPP_K0696110X70/K0696.110X70_top.dxf
70
10h9

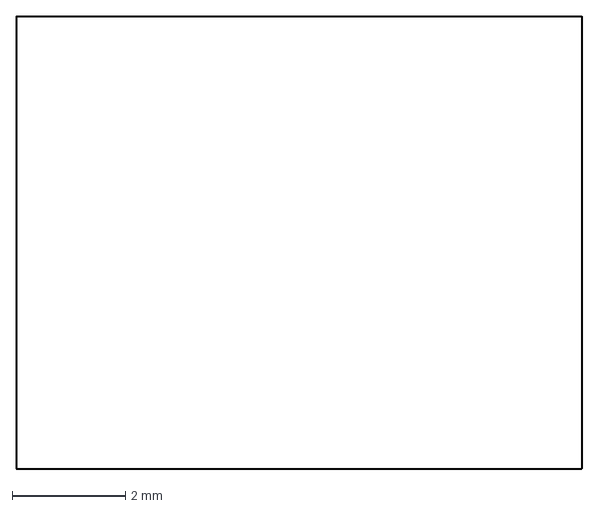
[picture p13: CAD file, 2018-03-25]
KIPP_K0696110X70/K0696.110X70_right.dxf
10.0 x 8.00 mm

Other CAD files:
StrojniSklopNacrt.dwg
izlazAlata.dwg
KIPP_K0696110X70/K0696.110X70.dxf
OldVersions/StrojniSklopNacrt.0001.dwg
6205.iam
6205_PART1.ipt
6205_PART2.ipt
6205_PART3.ipt
6209.iam
6209_PART1.ipt
6209_PART2.ipt
6209_PART3.ipt
ES2_-_Projektni_zadatak_-_Zaglavlje.idw
KIPP_K0696110X70/K0696_110X70.ipt
OldVersions/6205.0001.iam
OldVersions/6205_PART1.0001.ipt
OldVersions/6205_PART2.0001.ipt
OldVersions/6205_PART3.0001.ipt
OldVersions/6209.0001.iam
OldVersions/6209_PART1.0001.ipt
OldVersions/6209_PART2.0001.ipt
OldVersions/6209_PART3.0001.ipt
OldVersions/StrojniSklopNacrt.0067.idw
OldVersions/strojniSklop.0002.iam
OldVersions/vratilo.0012.ipt
OldVersions/vratiloAssembly.0009.iam
OldVersions/vratilo_kristijan.0022.ipt
StrojniSklopNacrt.idw
strojniSklop_primjer.iam
vratilo.ipt
vratiloAssembly.iam
vratilo_kristijan.ipt

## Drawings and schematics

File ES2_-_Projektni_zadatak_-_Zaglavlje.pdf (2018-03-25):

1

2

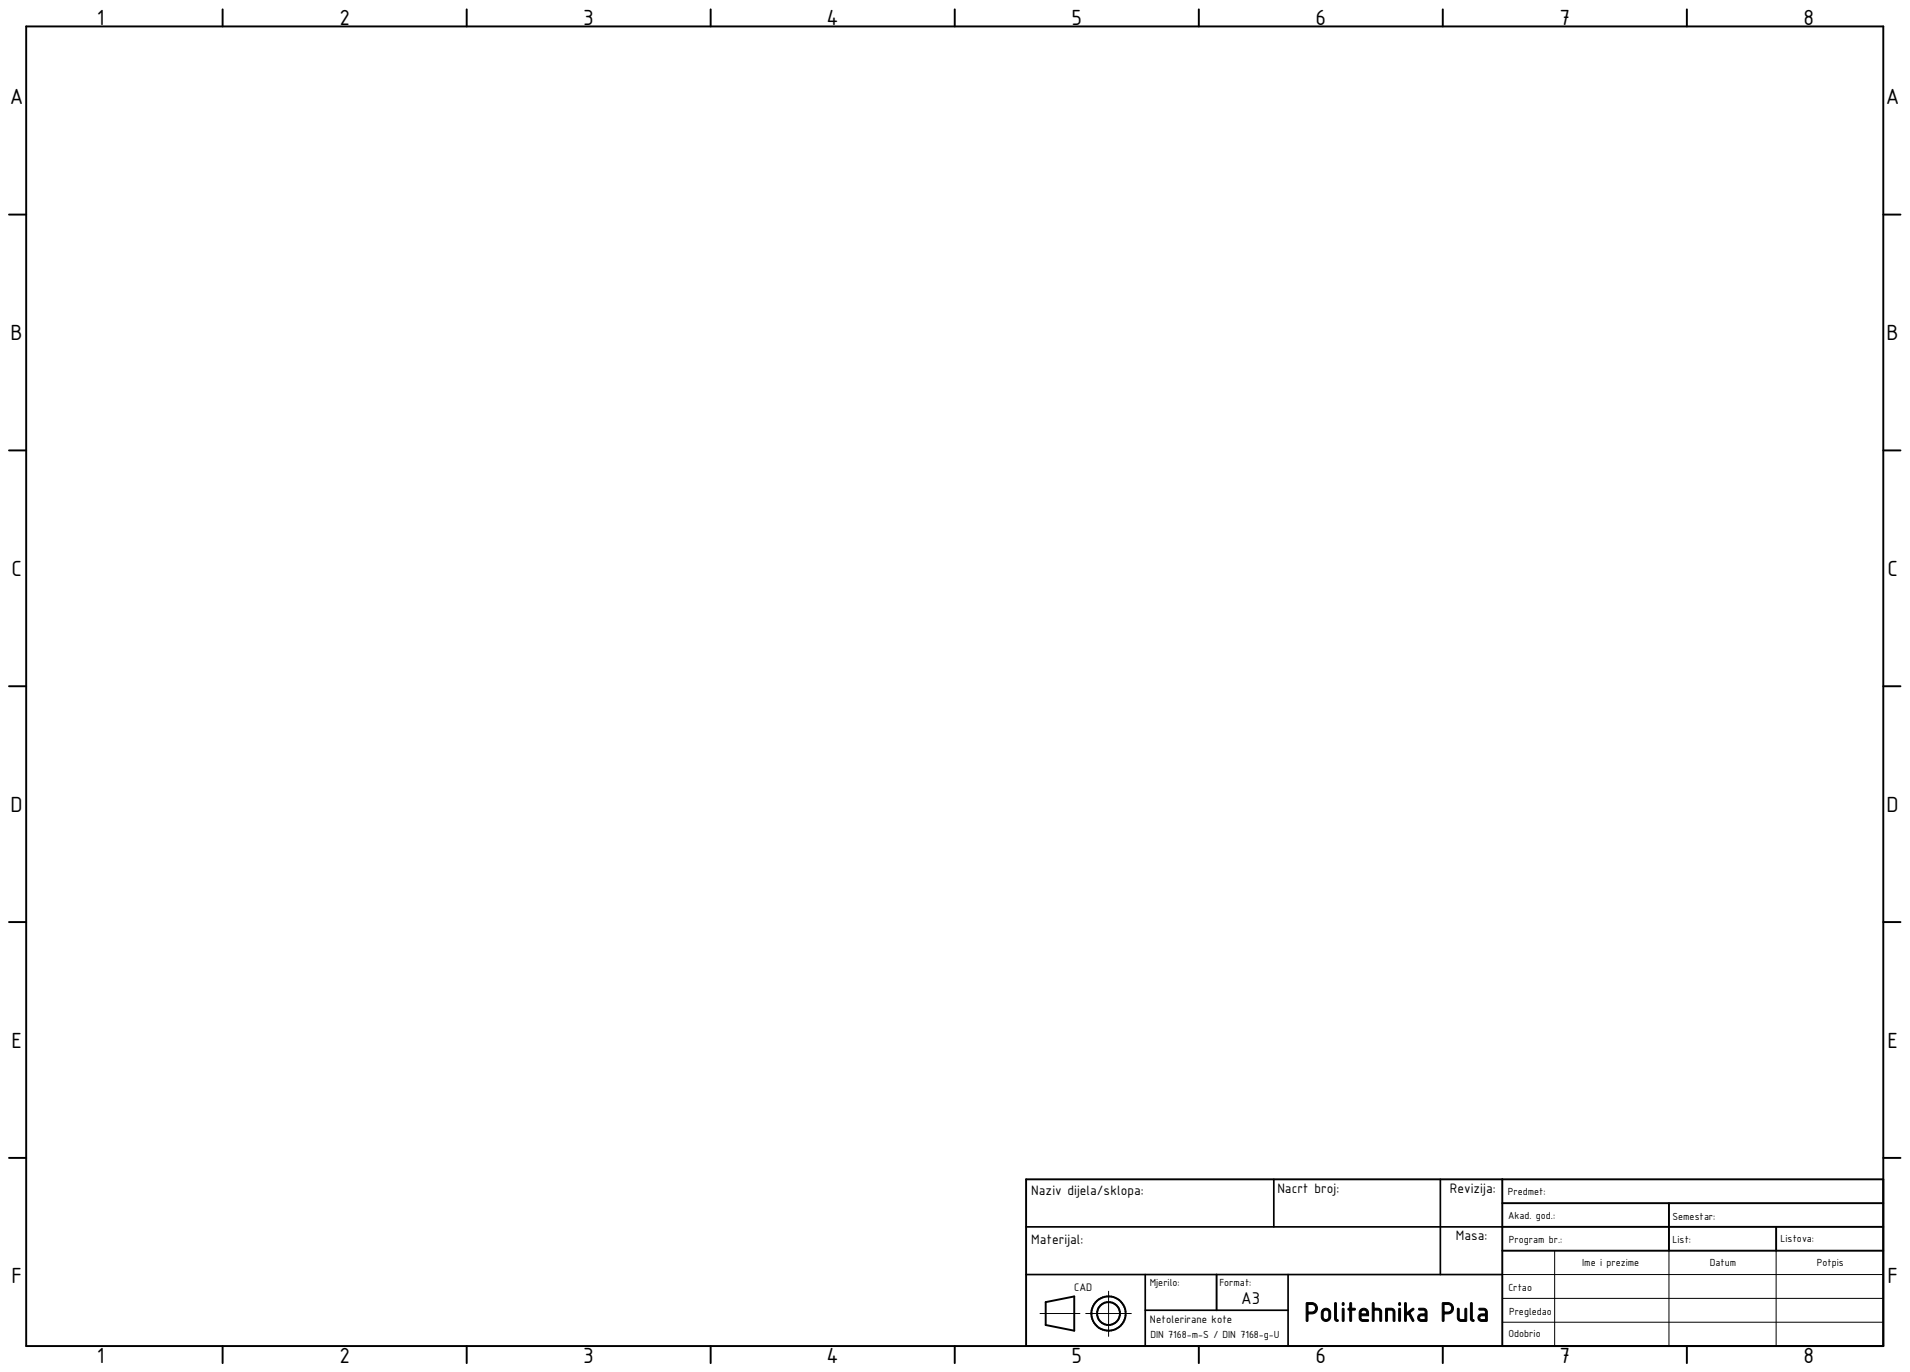
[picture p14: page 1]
F CAD; Netolerirane kote; DIN 7168-m-S / DIN 7168-g-U

Naziv dijela/sklopa: | Nacrt broj: | Revizija: | Predmet:

Akad. god.: | Semestar:

Materijal: | Masa: | Program br.: | List: | Listova:

Ime i prezime | Datum | Potpis

Mjerilo: | Format: A3 | Politehnika Pula | Crtao

Pregledao

Odobrio

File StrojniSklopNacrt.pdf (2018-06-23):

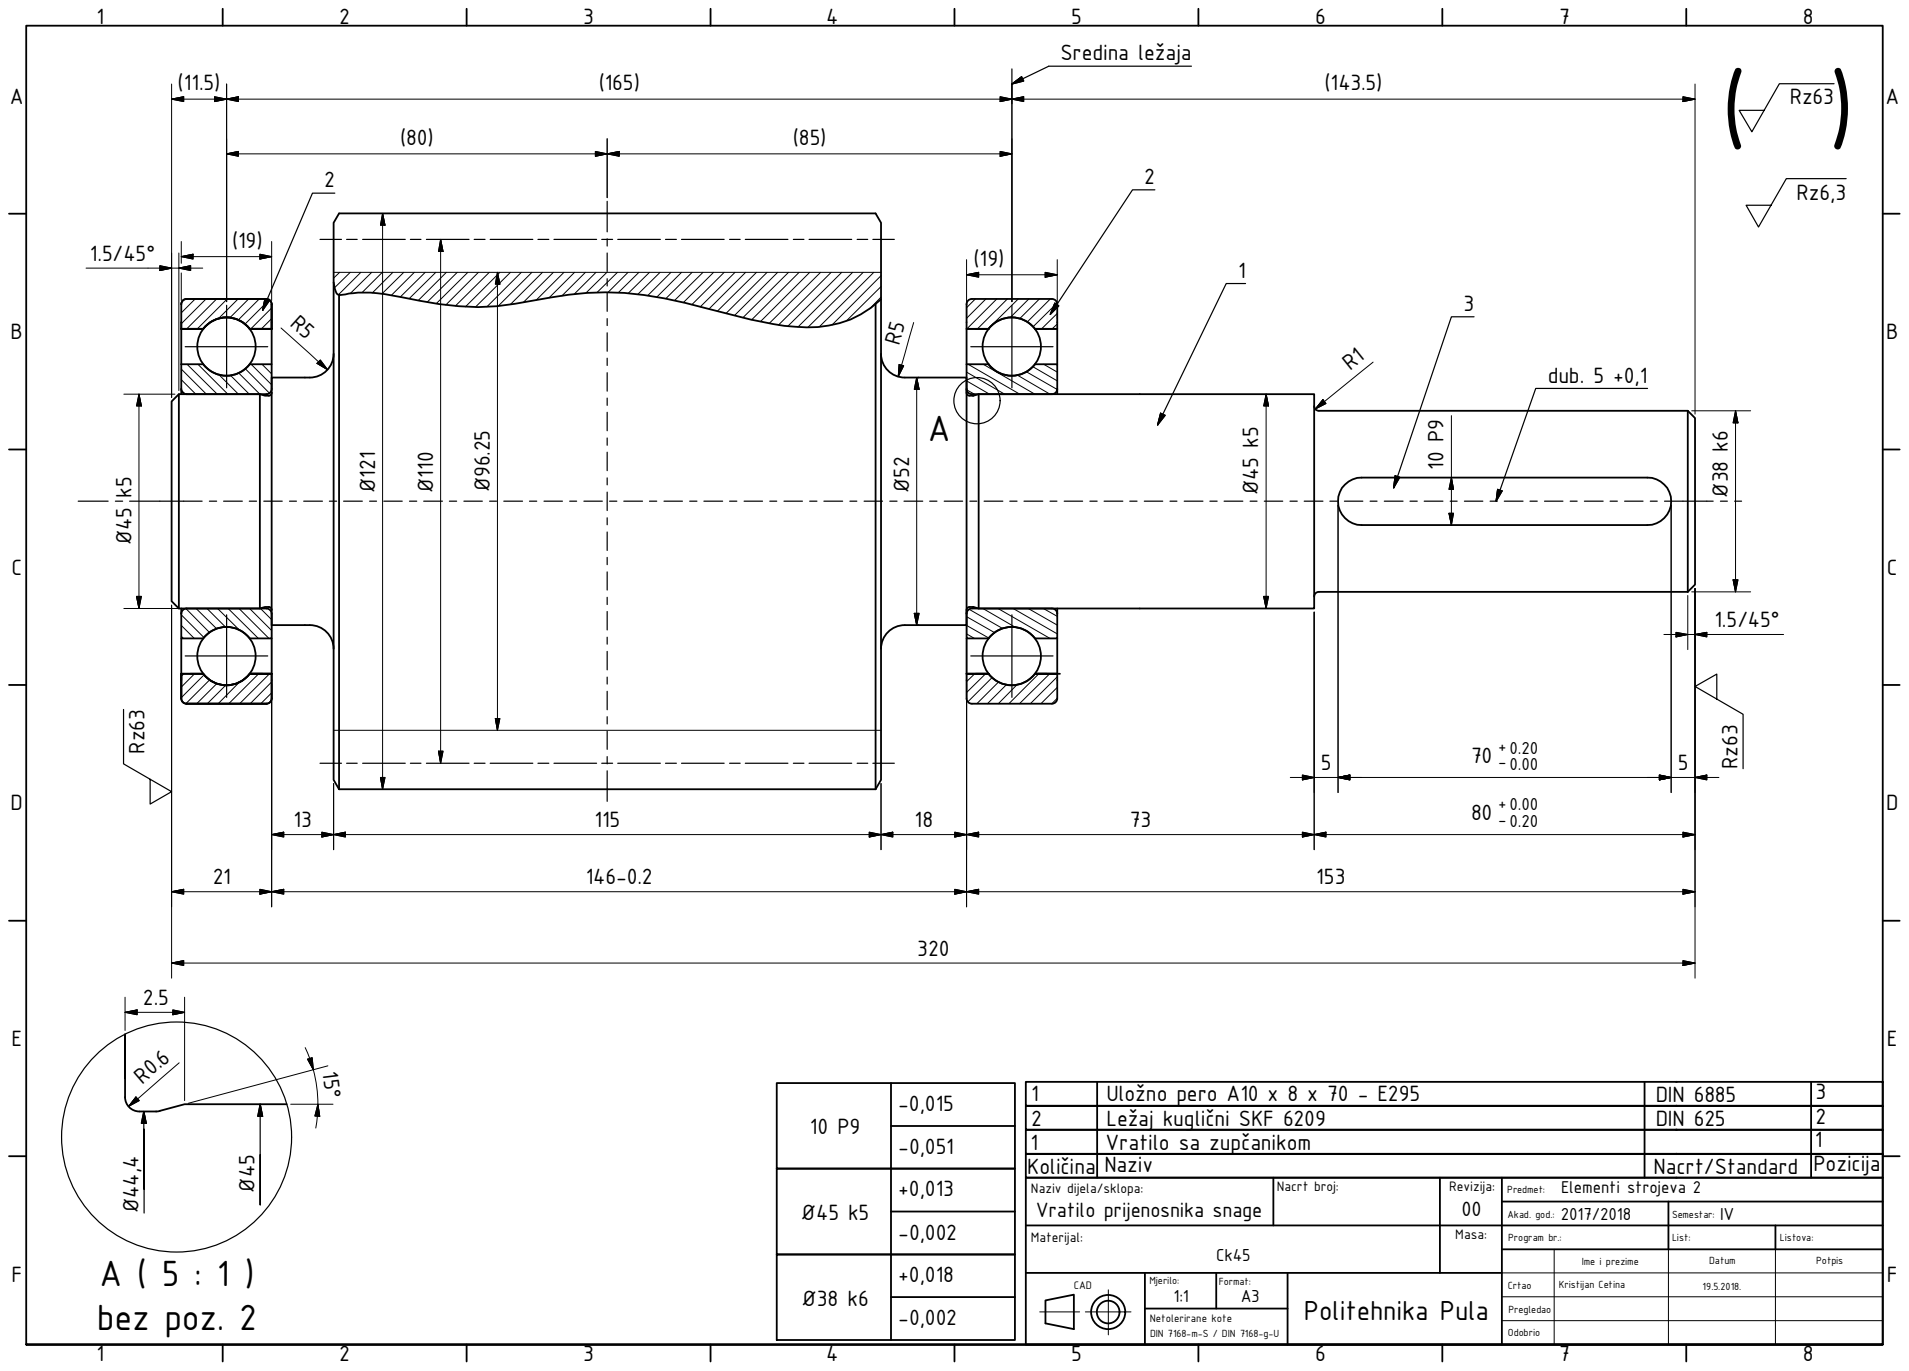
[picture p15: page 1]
A ( 5 : 1 ) bez poz. 2; F CAD; Netolerirane kote; DIN 7168-m-S / DIN 7168-g-U; dub. 5 +0,1; Vratilo sa zupúanikom

Sredina leaja

Koliúina | Naziv | Nacrt/Standard | Pozicija
Naziv dijela/sklopa: Vratilo prijenosnika snage | Nacrt broj: | Revizija: 00 | Elementi strojeva 2 Predmet:

2017/2018 Akad. god.: | IV Semestar:

Materijal: Ck45 | Masa: | Program br.: | List: | Listova:

Ime i prezime | Datum | Potpis

Mjerilo: 1:1 | Format: A3 | Politehnika Pula | Crtao | Kristijan Cetina | 19.5.2018.

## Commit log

2018-03-25 init
    inital commit
    [ES2_-_Projektni_zadatak_-_Zaglavlje.idw, K0696.110X70.dxf, K0696.110X70_back.dxf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]
2018-05-06 strojni sklop, izmjena proracuna
    [6205.0001.iam, 6205.iam, 6205_PART1.0001.ipt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]
2018-05-06 sklopni nacrt
    [6209.0001.iam, 6209.iam, 6209_PART1.0001.ipt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]
